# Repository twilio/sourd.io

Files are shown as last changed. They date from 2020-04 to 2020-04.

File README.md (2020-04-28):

# sourd.io: An internet connected sourdough starter data monitor

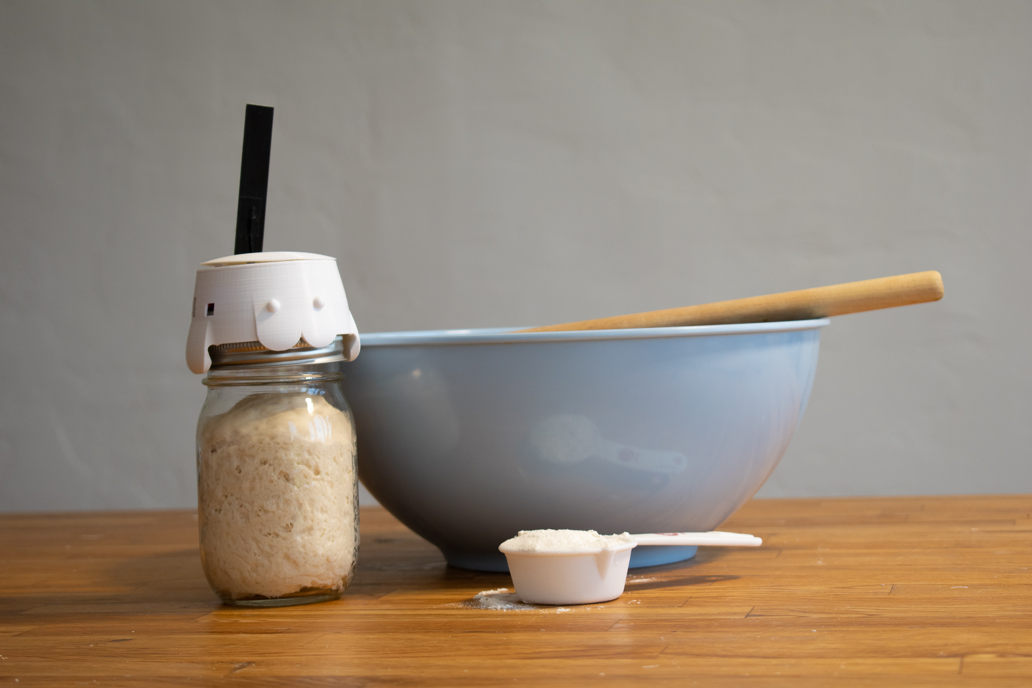
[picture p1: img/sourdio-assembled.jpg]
sourd.io monitor


### Build an internet connected fitness tracker for your loaf

A sourdough starter is a little yeast-driven pet that eats flour and water and makes sourdough. More and more people are keeping these delightful critters in their houses, feeding them when they start to look sluggish and baking bread with them every few days.

With Twilio's Narrowband IoT Developer Kit, we can build a little monitor that helps us keep track of our starter's temperature, humidity, and rise.

### Why Narrowband?

[Twilio's Narrowband IoT dev kit](https://www.twilio.com/docs/wireless/quickstart/alfa-developer-kit-mqtt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) happens to have some great sensors we can use to get started, and it's also designed for constant, low-power connectivity, which is what I want for this particular product. Cellular connectivity also means we don't have to do any setup or fight with our Wi-Fi routers.

The downside to Twilio Narrowband is that it only works in the US. If you're hoping to monitor your bread from outside the US, stay tuned! I'm planning another bread monitor in the future that connects with [Super SIM](https://www.twilio.com/wireless/super-sim?utm_source=github&utm_medium=repo&utm_campaign=sour01), which is available everywhere.

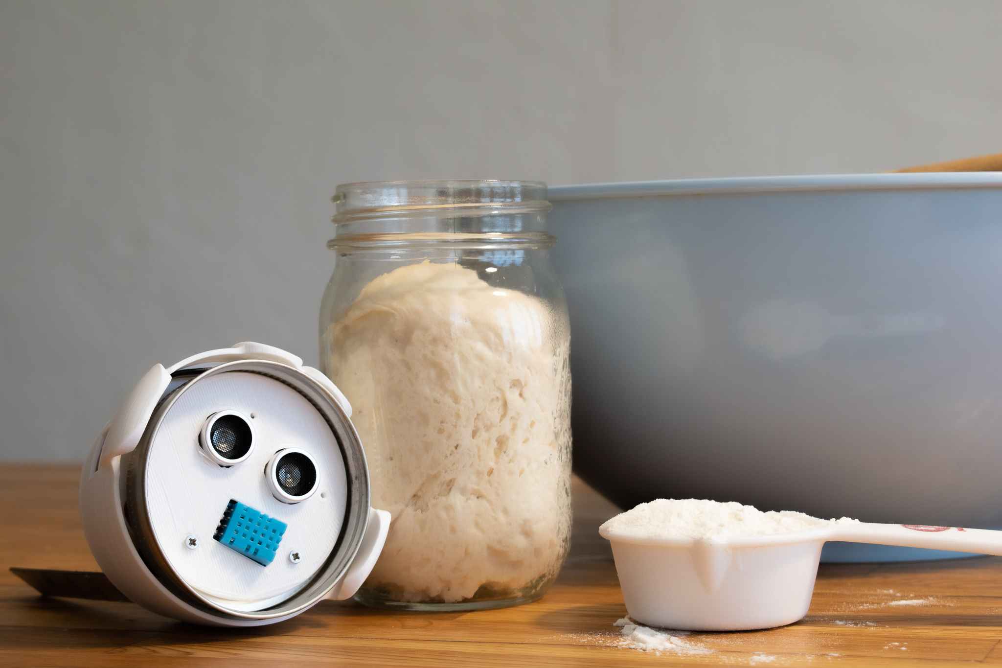
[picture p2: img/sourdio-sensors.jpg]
sourd.io monitor


### What you'll need

#### The Basics: What you need to get a proof-of-concept up and running
- If you haven’t yet, sign up for a Twilio Account. If you sign up for a new account through [this link](http://www.twilio.com/referral/9nItun), you’ll get an extra $10 in credit when you upgrade.
- 1 x [Twilio Developer Kit for Narrowband IoT](https://www.twilio.com/docs/wireless/quickstart/alfa-developer-kit-mqtt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). Dev kits are currently ordered through the console. To order, first add your payment info to your Twilio account, then go to the [Wireless order page](https://www.twilio.com/console/wireless/orders?utm_source=github&utm_medium=repo&utm_campaign=sour01) and fill out the form.
- 1 x LiPo battery 3.7V 1900MAH (35mm x 50mm) (Note: this is not the one that comes in the kit)
- The [Arduino IDE](https://www.arduino.cc/en/main/software)
- This repo
- An MQTT broker of choice. This build has been tested with Adafruit IO and Thingspeak, and has info on how to set that up in the `/nbiot-sourdough-monitor` folder of the repo.
- The United States. Twilio Narrowband currently works in the US.

#### Enclosures: What you need to make it pretty
- A way to print the .stl files found in the `/enclosure` folder of this repo. You can use a 3D printer, or go through a third-party service like 3D Hubs.
- 11 x M2.2 8mm screws
- 1 x Ball jar with 2 1/2 inch canning lid (the one where the center is removable)
- Hot Glue Gun (if you want your sourd.io to have ears and a hat)

### Putting it together

#### Bringing your Narrowband Kit online

Rather than replicating the tutorial here, I'm going to suggest that you follow the steps in the [Narrowband Kit Quickstart](https://www.twilio.com/docs/wireless/quickstart/alfa-developer-kit-mqtt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) to get your Twilio SIM registered and your libraries installed. The one exception to these instructions is that you should use your other LiPo battery rather than the thin, square one that comes in the Narrowband Kit.

**Windows 10 users** may run into problems connecting to their Narrowband Kit. If you do, follow this guide by [Scott Hanselman](https://www.hanselman.com/blog/HowToFixDfuutilSTMWinUSBZadigBootloadersAndOtherFirmwareFlashingIssuesOnWindows.aspx) to get going. You'll want to do this before the "[Connect to the MQTT broker and publish messages](https://www.twilio.com/docs/wireless/quickstart/alfa-developer-kit-mqtt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)" section in the Quickstart.

Check that the code compiles. You can even try uploading it and resetting the board to see if you can get it to come online. Once your board is making happy blue lights, then come back to this tutorial.

#### Hook up your hardware

This kit comes with several sensors. We're going to use the Ultrasonic Distance sensor and the Temperature/Humidity sensor. Plug the distance sensor into D38 and the temp/humidity sensor into D20.

#### Add custom bread firmware

Download or clone this repo and open the folder `nbiot-sourdough-monitor` in Arduino. Add your MQTT info to the file `mqttcreds-edit-and-rename.h` and then-- you guessed it-- rename it to `mqttcreds.h`. 

To fill out this file, you'll probably need to actually set up a broker. Instructions in the file tell you what you need to set up Adafruit IO or Thingspeak to work with this monitor, since those have an easy way to create public visualizations so you can share your bread's health with friends. Feel free to use a different broker of your choice as well!

You also may need to install additional libraries for the Grove Temperature/Humidity and Ultrasonic Ranger sensors. Those can be found at the following links:

https://github.com/Seeed-Studio/Grove_Temperature_And_Humidity_Sensor
https://github.com/Seeed-Studio/Grove_Ultrasonic_Ranger

You can download these as .zip files and use `Sketch > Include Library > Add .ZIP Library...` to add them. Afterward, restart the Arduino IDE.

Next, put your board in bootloader mode by holding the bootloader button and tapping the reset button. Compile and upload `nbiot-sourdough-monitor.ino`.

If all is working, then your board should come online with a happy blue light. Open the Serial Monitor to see if the board is sending commands.

#### See your data

Navigate to your chosen MQTT broker and check out the commands coming into your channel or dashboard!

#### Assembling the enclosure

Print the .stl files in the `/enclosure` folder.

Remove the Grove Header from the Temperature/Humidity Sensor and solder the wires directly to the back of the board (opposite the blue sensor).

Assemble like this:

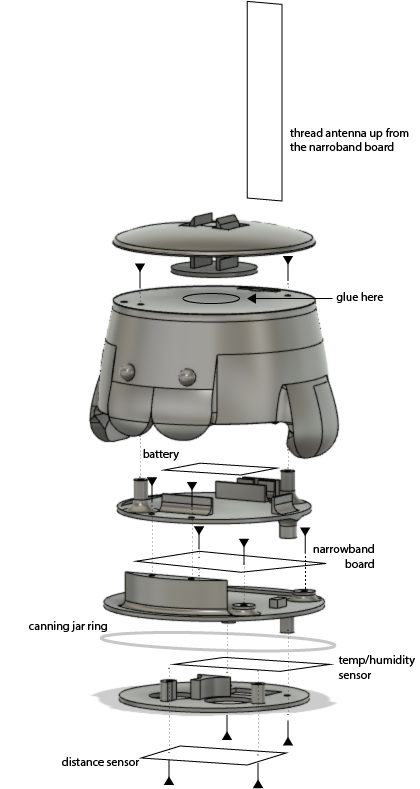
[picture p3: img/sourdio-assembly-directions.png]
sourd.io assembly instructions


Screw the bread monitor onto your jar and put your sourdough starter in the jar!

#### Monitor your bread

Humidity is a particularly interesting one to watch. In the enclosed environment of the jar, the humidity produced as the yeast respirates is delightfully detectable. My monitor may be online right now; feel free to look at the data [here](https://thingspeak.com/channels/1037031).

#### Fine Print

Someone told me I should add license info here! Please simply don't be a jerk when using this repo and if you're interested in doing Something Serious with it, I'd love to hear. Reach out to me on [Twitter](https://twitter.com/christinesunu) or here on Github.

Putting this under the Apache 2.0 license, which is also what is used by the [Twilio repo that the code sample is adapted from](https://github.com/twilio/breakout-massive-iot)

Copyright 2020 Christine Sunu

Licensed under the Apache License, Version 2.0 (the "License");
you may not use this file except in compliance with the License.
You may obtain a copy of the License at

    http://www.apache.org/licenses/LICENSE-2.0

Unless required by applicable law or agreed to in writing, software
distributed under the License is distributed on an "AS IS" BASIS,
WITHOUT WARRANTIES OR CONDITIONS OF ANY KIND, either express or implied.
See the License for the specific language governing permissions and
limitations under the License.

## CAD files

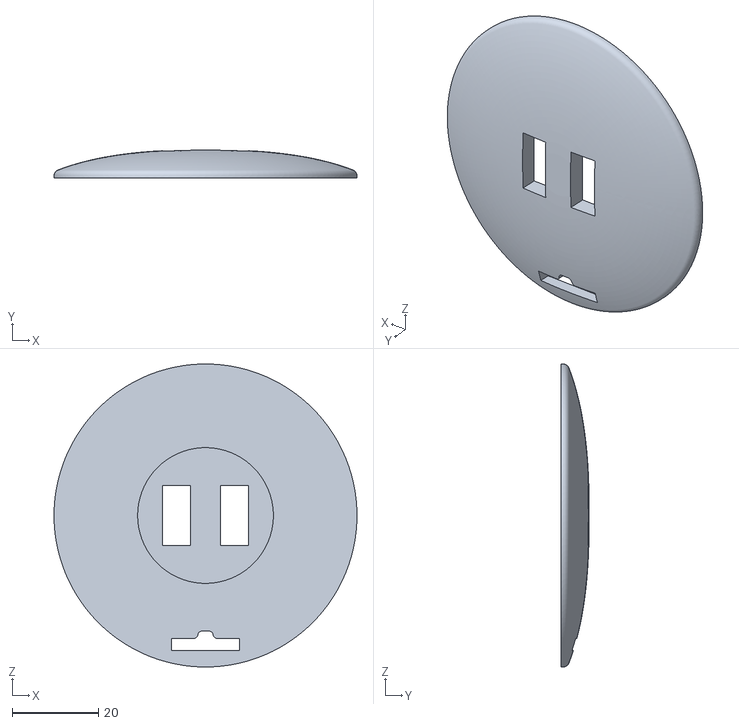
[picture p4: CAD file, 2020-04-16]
enclosure/v2.5/hat-v25.stl
70.3 x 6.50 x 70.3

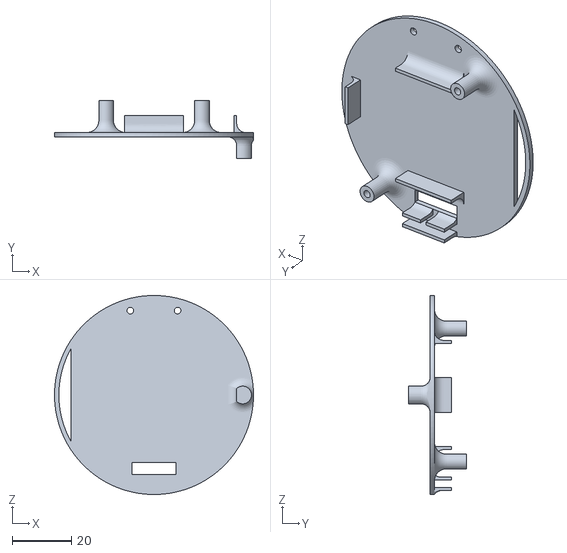
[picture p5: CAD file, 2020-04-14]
enclosure/v2.5/layer3_v25.stl
67.3 x 19.5 x 67.4

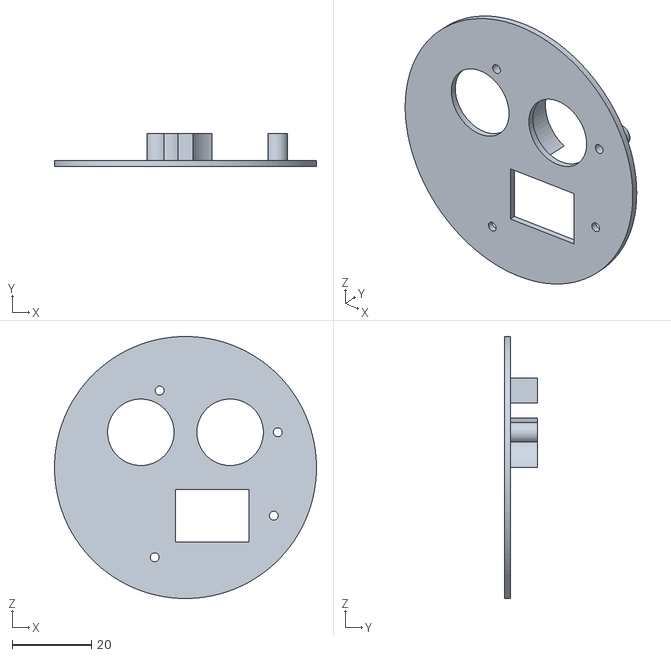
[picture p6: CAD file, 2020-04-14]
enclosure/v2.5/layer1_v25.stl
66.0 x 8.25 x 66.0

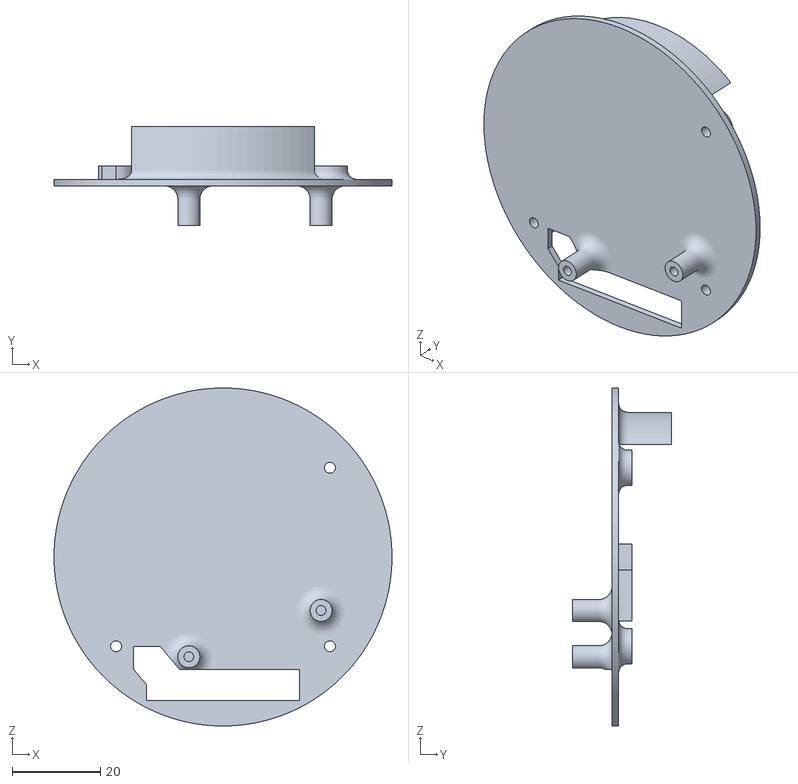
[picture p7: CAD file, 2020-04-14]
enclosure/v2.5/layer2_v25.stl
76.7 x 22.5 x 76.7

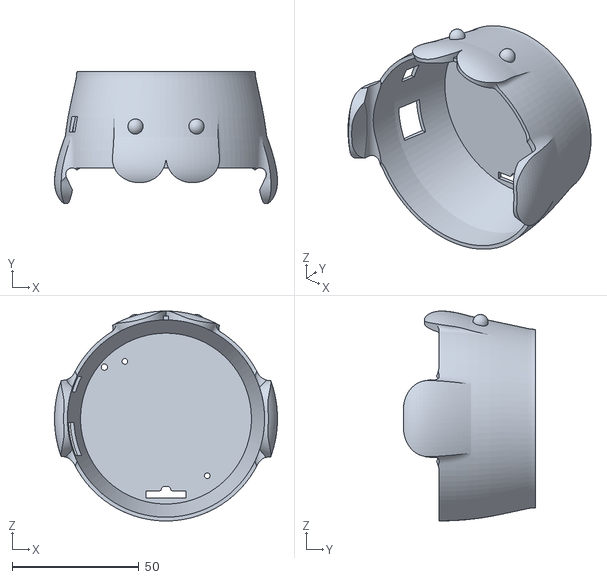
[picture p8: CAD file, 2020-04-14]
enclosure/v2.5/layer4_v25.stl
87.8 x 52.0 x 82.7

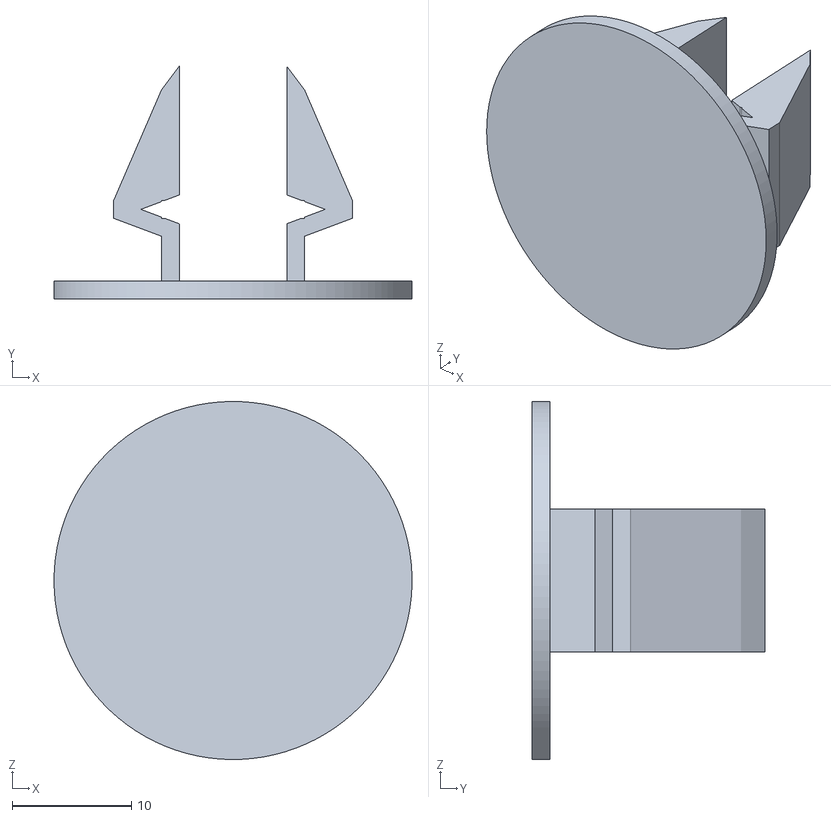
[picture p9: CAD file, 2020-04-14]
enclosure/v2.5/insert_v25.stl
30.0 x 19.5 x 30.0

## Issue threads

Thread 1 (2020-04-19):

Link to suggested battery to buy

sepulworld, 2020-04-19:
Hi! Thank you for sharing this project!

Curious, do you have a link to a suggested battery to purchase?

cmsunu28, 2020-04-28:
Hi! Thanks for opening this issue. I think this battery should work! https://www.adafruit.com/product/2011

sepulworld, 2020-04-29:
Thanks for sharing! I picked up a similar one on Amazon.

Closed 2020-04-29.

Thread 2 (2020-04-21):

Windows 10 users may have issues connection to STM32 microcontrollers over USB; suggest a fix in README

aholmes, 2020-04-21:
Windows 10 uses a default driver for STM32 microcontrollers and doesn't always make it possible to upload new firmware. There are several guides on fixing this, but the one provided in the kit's quickstart is obtuse and unhelpful. Add a more user-friendly one to the README.md.

Closed 2020-04-28.

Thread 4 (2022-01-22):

Can you please post a layer 1 stl for the generic ultrasonic  module HC-SR04?

omer-re, 2022-01-22:
the holes for the ultrasonic are too close for the generic (cheaper) version,
I would really appreciate if you can modify it to fit the generic module.

https://www.aliexpress.com/item/32477198302.html?spm=a2g0o.order_list.0.0.21ef1802xtWqhj

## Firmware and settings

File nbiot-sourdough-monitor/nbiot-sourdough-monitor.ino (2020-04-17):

// This sketch is based on the original Twilio Breakout SDK sample for the Narroband IoT kit,
// with a number of alterations, edits, and a lot of comments
// Twilio Breakout SDK for Massive IoT: https://github.com/twilio/breakout-massive-iot

// ok now for code

// Tell it to include the important stuff from this sketch
#include "config.h"
#include "mqttcreds.h"
#include "modem.h"
#include "mqtt.h"

/**** Libraries for the bread monitor ****/

// We also need to include libraries for the temperature and humidity sensor, as well as the ultrasonic sensor
// https://github.com/Seeed-Studio/Grove_Temperature_And_Humidity_Sensor
#include <DHT.h>
// Install via zip if not working: https://github.com/Seeed-Studio/Grove_Ultrasonic_Ranger
#include <Ultrasonic.h>

/**** Variables for the bread monitor ****/

// Temp/humidity will be on D20 Grove port
#define SENSOR_PIN (D20)
#define DHTTYPE DHT11  // DHT 11
DHT dht(SENSOR_PIN, DHTTYPE);

// Ultrasonic will be on D38 Grove port
#define ULTRASONIC_PIN 38
Ultrasonic UltrasonicRanger(ULTRASONIC_PIN);

// we will send it every 20 second or so
#define SEND_INTERVAL (20 * 1000)


/**** Code to run once, when the device boots up ****/

void setup() {

  // run code to set up mqtt and modem stuff
  
  owl_log_set_level(L_INFO);

  modem_setup();
  mqtt_setup();

  // then, tell the serial log that we are going to start

  LOG(L_WARN, "Hi! I am the bread monitor. Now trying to start....\r\n");

  // run our bread monitor setup...
  LOG(L_WARN, "Powering on bread sensors....\r\n");
  dht.begin();
  pinMode(ULTRASONIC_PIN, INPUT);
  
  return;
}

/**** Code to run repeatedly, after the device boots ****/

void loop() {

// If you aren't connected yet, keep trying to connect!
  if (!mqtt_loop()) {
    goto continue_loop;
  }

// also, run the bread monitor loop
  bread_monitor_loop();

// This is the loop you'll run if you aren't connected yet
continue_loop:
  rn4_modem->AT.spin();
  if (mqtt != nullptr) {
    mqtt->yield(LOOP_INTERVAL);
  }
}


void bread_monitor_loop() {
  static unsigned long last_send = 0;

  if (!sleep && ((last_send == 0) || (millis() - last_send >= SEND_INTERVAL))) {
    float temperature = dht.readTemperature();
    float humidity    = dht.readHumidity();
    long distance     = UltrasonicRanger.MeasureInCentimeters();
    last_send = millis();

    #if defined(CUSTOM_MQTT)
    // sending data to a custom MQTT broker. Edit this to work with your broker!
    // this part will only be compiled if we are pubishing to a custom broker! (see mqttcreds-edit-and-rename.h)
    char commandText[512];
    // edit the below text to fit your broker's needs!
    snprintf(commandText, 512, "{\"device\":\"%.*s\",\"humidity\":%4.2f,\"temp\":%4.2f,\"distance\":%ld}", imei.len, imei.s, humidity,temperature, distance);
    if (!send_data(commandText)) {
      LOG(L_WARN, "Error publishing message: (client connected status: %d)\r\n", mqtt->isConnected());
    }
    #endif

    #if defined(ADAFRUIT_MQTT)
    // sending data to Adafruit.io feeds, using Adafruit's json formatting
    // this part will only be compiled if we are pubishing to Adafruit! (see mqttcreds-edit-and-rename.h)
    char humidityText[512];
    char tempText[512];
    char distanceText[512];
    snprintf(humidityText, 512, "{\"value\":%4.2f}", humidity);
    snprintf(tempText,512, "{\"value\":%4.2f}",temperature);
    snprintf(distanceText,512, "{\"value\":%ld}",distance);
    if (!send_data(humidityText,MQTT_HUMIDITY_TOPIC)) {
      LOG(L_WARN, "Error publishing message: (client connected status: %d)\r\n", mqtt->isConnected());
    }
    if (!send_data(tempText,MQTT_TEMP_TOPIC)) {
      LOG(L_WARN, "Error publishing message: (client connected status: %d)\r\n", mqtt->isConnected());
    }
    if (!send_data(distanceText,MQTT_DISTANCE_TOPIC)) {
      LOG(L_WARN, "Error publishing message: (client connected status: %d)\r\n", mqtt->isConnected());
    }
    #endif

    #if defined(THINGSPEAK_MQTT)
    // sending individually to Thingspeak channels, using Thingspeak query formatting
    // this part will only be compiled if we are pubishing to Thingspeak! (see mqttcreds-edit-and-rename.h)
    char pubText[512];
    snprintf(pubText, 512, "field1=%4.2f&field2=%4.2f&field3=%ld&status=MQTTPUBLISH", humidity, temperature, distance);
    if (!send_data(pubText,MQTT_PUBLISH_TOPIC)) {
      LOG(L_WARN, "Error publishing message: (client connected status: %d)\r\n", mqtt->isConnected());
    }
    #endif

  }
}

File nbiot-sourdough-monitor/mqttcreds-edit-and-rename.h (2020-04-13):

// Make a copy of this file and call it mqttcreds.h 
// Make sure it is in the same directory as your .ino

// This file tells your .ino which broker to publish to, and how to communicate with it
// You can use whatever broker you want! 
// I tested with Thingspeak and Adafruit, so I've included the info for using those here
// You can also create your own custom broker

/*** Picking A Broker ***/

// Adafruit docs: https://io.adafruit.com/api/docs/mqtt.html
// Set up Adafruit creds below and Uncomment this next line to use Adafruit:
    //  #define ADAFRUIT_MQTT
// Thingspeak docs: https://www.mathworks.com/help/thingspeak/mqtt-api.html
// Set up Thingspeak creds below and Uncomment this next line to use Thingspeak:
//    #define THINGSPEAK_MQTT
// Or do your own thing! Set up custom creds below and uncomment this next line to do something custom:
    #define CUSTOM_MQTT

/***-- CUSTOM BROKER --***/
#if defined(CUSTOM_MQTT)

    /*** To Auth, Or Not To Auth? ***/

    // If you're doing a custom broker, you may need different kinds of auth. 
    // To enable an autentication mechanism, un-comment the #define below.
    // The following are supported mechanisms:
    //
    // USE_USERNAME_PASSWORD - Enables cleartext username/password authentication.
    // USE_TLS_USERNAME_PASSWORD - Enables TLS and uses username/password for authentication
    // USE_TLS_CLIENT_CERTIFICATES - Enables TLS and uses client certificates for authentication

    #define USE_USERNAME_PASSWORD
    //#define USE_TLS_USERNAME_PASSWORD
    //#define USE_TLS_CLIENT_CERTIFICATES

    /*** My Broker ***/

    #define MQTT_BROKER_HOST "your.broker.here"

    // MQTT_BROKER_PORT generally is 1883 for clear-text, 8883 for TLS
    #define MQTT_BROKER_PORT 1883
    // Keep-Alive parameter for your connection. Depends on your network conditions,
    //   20 is normally a safe bet
    #define MQTT_KEEP_ALIVE 20

    /*** My Client Id ***/
    // Client ID uniquely identifies your device on the broker. If not unique, the broker will deny the connection
    #define MQTT_CLIENT_ID "your-unique-client-id"

    /*** My Topic ***/
    // The topic to publish your data to
    // You'll need, at the very least, a main topic and a state topic
    // You can customize how these are handled in the .ino file
    #define MQTT_PUBLISH_TOPIC "your-topic-name"
    #define MQTT_STATE_TOPIC "your-topic-name/state"

    /*** To Auth Or Not To Auth: The Sequel ***/
    // handles our auth from earlier
    #if defined(USE_USERNAME_PASSWORD) || defined(USE_TLS_USERNAME_PASSWORD)
    // Login to use for login/password authentication
    #define MQTT_LOGIN "YOUR-CREDS-HERE"
    // Password to use for login/password authentication
    #define MQTT_PASSWORD "YOUR-CREDS-HERE"
    #endif

#endif

/***-- ADAFRUIT.IO --***/
#if defined(ADAFRUIT_MQTT)

    // adafruit uses auth
    #define USE_USERNAME_PASSWORD
    // adafruit: "io.adafruit.com"
    #define MQTT_BROKER_HOST "io.adafruit.com"
    // MQTT_BROKER_PORT generally is 1883 for clear-text, 8883 for TLS
    #define MQTT_BROKER_PORT 1883
    // Keep-Alive parameter for your connection. Depends on your network conditions,
    //   20 is normally a safe bet
    #define MQTT_KEEP_ALIVE 20

    // adafruit client id: your username
    #define MQTT_CLIENT_ID "<your-adafruit-username>"

    // adafruit topic names
    // these are the adafruit ones for a group called "breadmonitor"
    #define MQTT_PUBLISH_TOPIC "<your-adafruit-username>/feeds/breadmonitor/json"
    #define MQTT_HUMIDITY_TOPIC "<your-adafruit-username>/feeds/breadmonitor.humidity/json"
    #define MQTT_TEMP_TOPIC "<your-adafruit-username>/feeds/breadmonitor.temp/json"
    #define MQTT_DISTANCE_TOPIC "<your-adafruit-username>/feeds/breadmonitor.distance/json"
    #define MQTT_STATE_TOPIC "<your-adafruit-username>/feeds/breadmonitor/state"

    #if defined(USE_USERNAME_PASSWORD) || defined(USE_TLS_USERNAME_PASSWORD)
    // Login to use for login/password authentication
    // adafruit login: your username
    #define MQTT_LOGIN "<your-adafruit-username>"
    // adafruit password: your API key
    #define MQTT_PASSWORD "<your-adafruit-api-key>"
    #endif

#endif

/***-- THINGSPEAK --***/
#if defined(THINGSPEAK_MQTT)

    // thingspeak uses auth
    #define USE_USERNAME_PASSWORD
    // thingspeak: "mqtt.thingspeak.com"
    #define MQTT_BROKER_HOST "mqtt.thingspeak.com"
    // MQTT_BROKER_PORT generally is 1883 for clear-text, 8883 for TLS
    #define MQTT_BROKER_PORT 1883
    // Keep-Alive parameter for your connection. Depends on your network conditions,
    //   20 is normally a safe bet
    #define MQTT_KEEP_ALIVE 20

    // thingspeak client id: generate a random unique client ID
    //     you can use something like https://www.uuidgenerator.net/ to get one
    #define MQTT_CLIENT_ID "<your-randomly-generated-ID>"

    // thingspeak formatting looks like this for topics
    // thingspeak topic name for channel feeds: "channels/<channelID>/publish/<apikey>"
    //     where <apikey> is the API key of that specific channel
    // thingspeak topic name for channel fields: "channels/<channelID>/publish/fields/field<fieldnumber>/<apikey>"
    //     where <apikey> is the API key of that specific channel
    //     and <fieldnumber> is the number of the field you want to update

    // So our thingspeak topic names look like this
    #define MQTT_PUBLISH_TOPIC "channels/<channelID>/publish/<channel-API-key>"
    #define MQTT_STATE_TOPIC "channels/<channelID>/publish/fields/field4/<channel-API-key>"

    #if defined(USE_USERNAME_PASSWORD) || defined(USE_TLS_USERNAME_PASSWORD)
    // Login to use for login/password authentication
    // thingspeak login: any username is fine, doesn't have to be your actual
    #define MQTT_LOGIN "<any-random-username>"
    // thingspeak password: your API key
    #define MQTT_PASSWORD "<your-thingspeak-account-api-key>"
    #endif

#endif

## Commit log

2020-04-13 with clear instructions on mqtt broker and stuff
    [mqttcreds-edit-and-rename.h, nbiot-sourdough-monitor.ino]
2020-04-14 with in-progress instructions and enclosure info
    [hat_v23.stl, insert_v23.stl, layer1_v23.stl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]
2020-04-16 added all stls
    [hat-v25.stl, hat_v23.stl, insert_v25.stl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]
